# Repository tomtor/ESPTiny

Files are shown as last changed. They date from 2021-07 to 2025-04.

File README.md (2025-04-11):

# ATtiny84/16x4/x02 and ESP-01 (ESP8266) KiCad PCB and example code

## Usage

The main function of the ATtiny is acting as a battery friendly low power co-processor for the ESP.
A bit like the ULP low power co-processor of the ESP32, except with a lot more IO functions and program memory.

ATtiny and ESP combined use 22uA in sleep mode or even less when the ESP
is switched off by the ATtiny with CS.

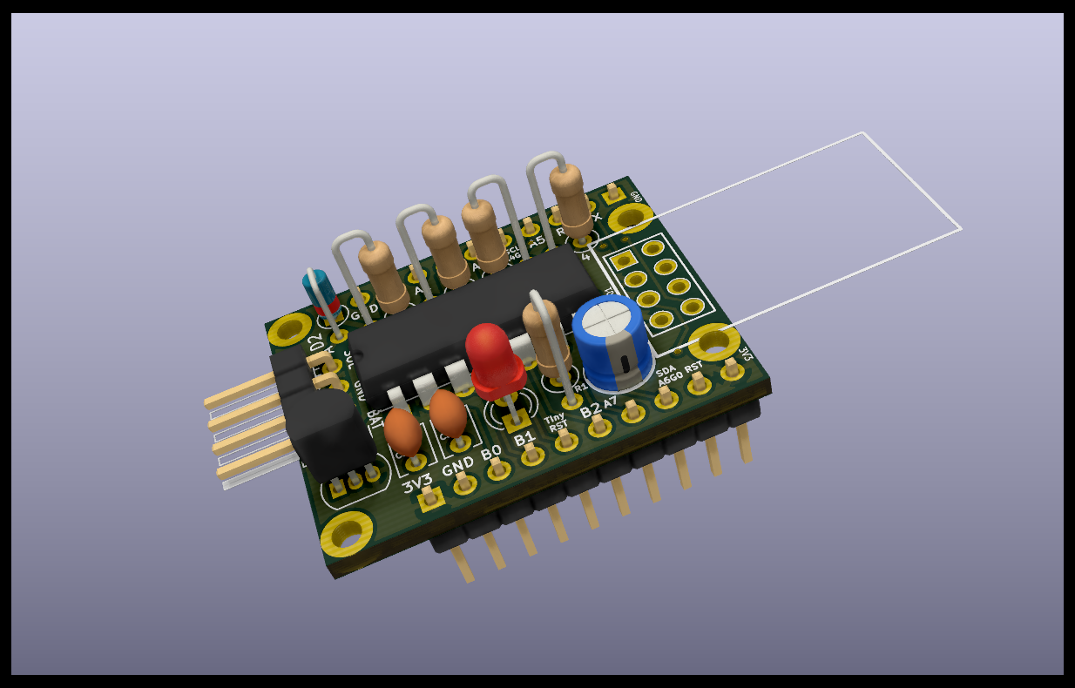
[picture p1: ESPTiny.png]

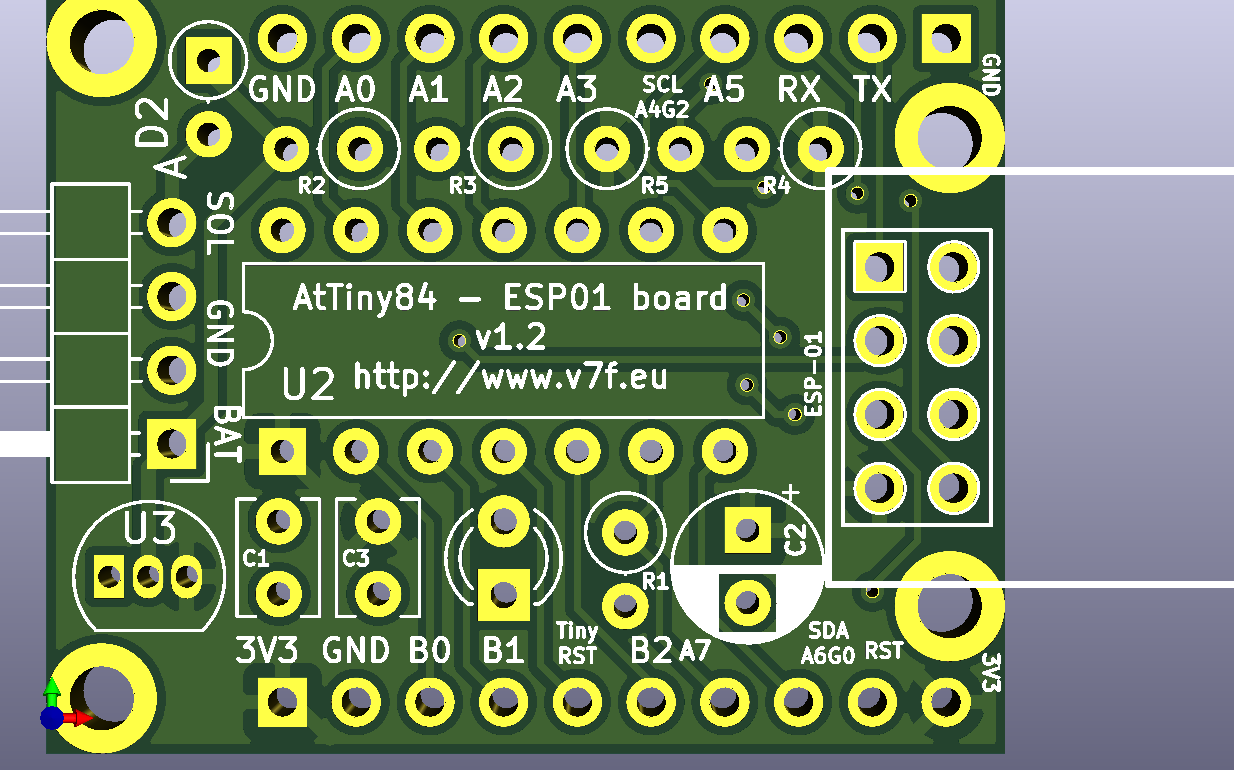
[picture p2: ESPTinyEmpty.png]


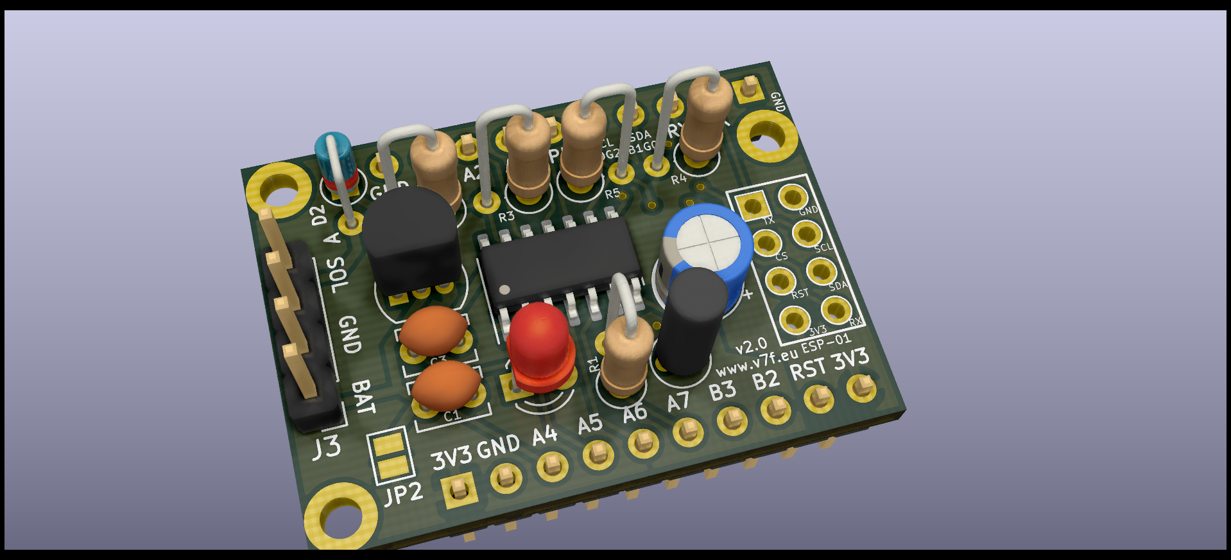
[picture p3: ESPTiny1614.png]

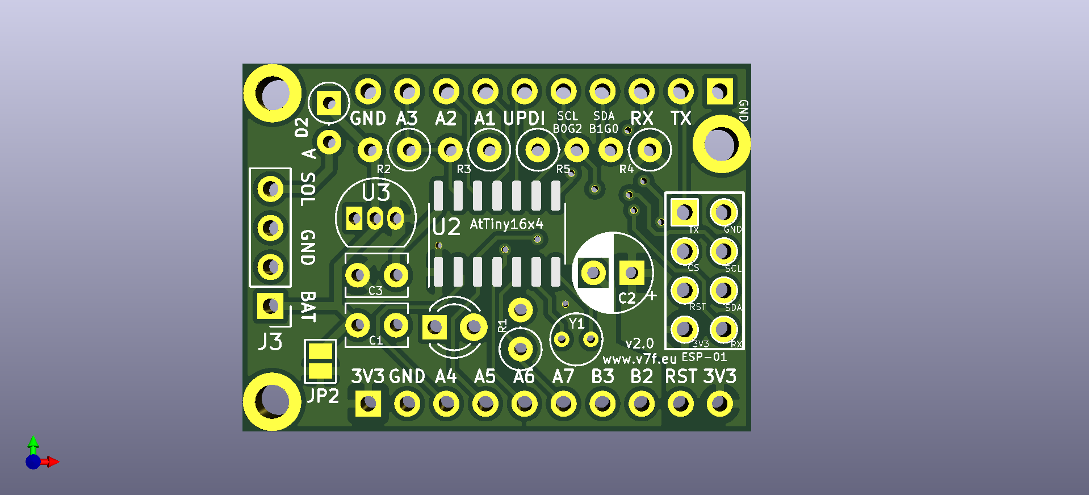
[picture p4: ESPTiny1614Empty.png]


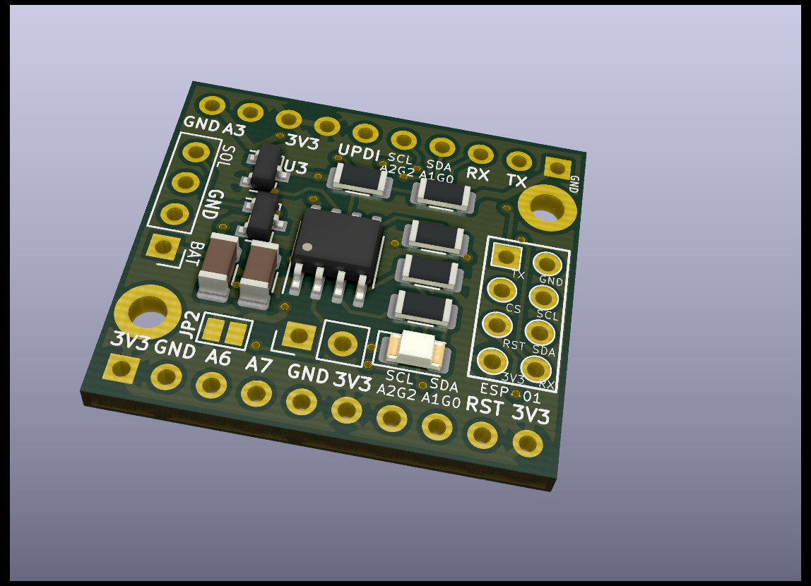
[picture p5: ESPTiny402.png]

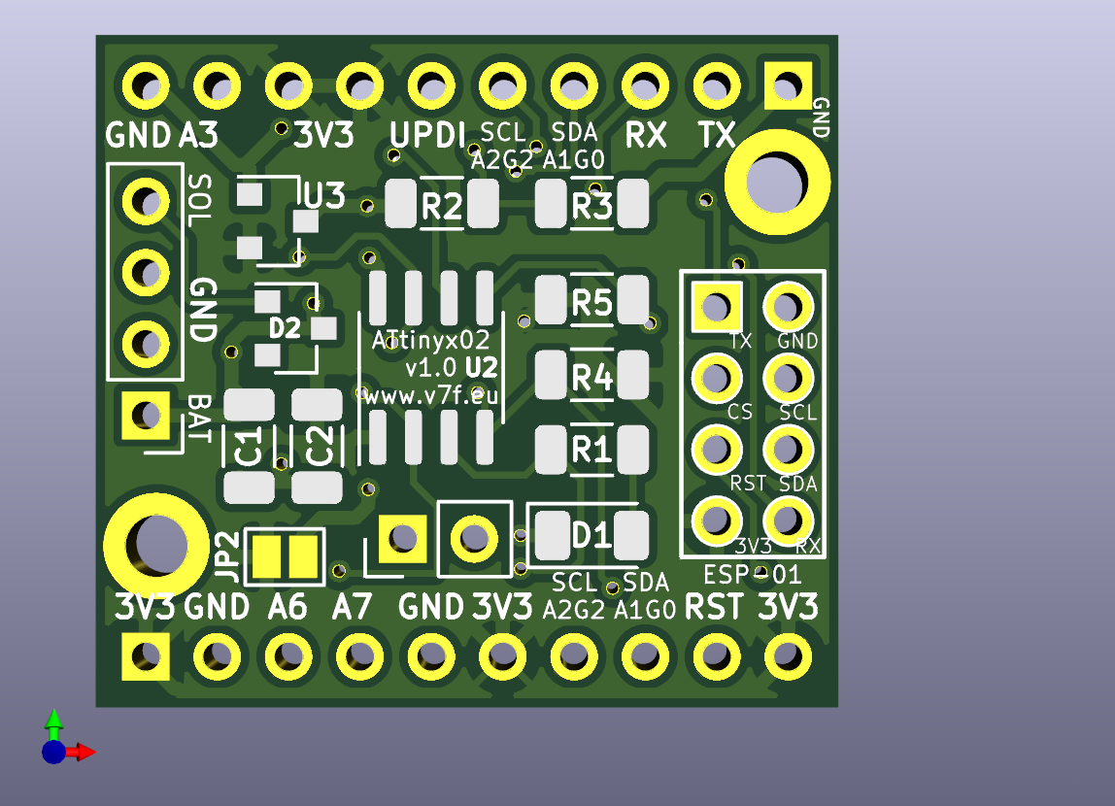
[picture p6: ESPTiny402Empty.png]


Usable on breadboard (ATtiny84: 9 rows high, leaves 2 rows empty and ATtiny16x4: 8 rows high) OR stand alone.

3 PCB designs: ATtiny84 or ATtiny16x4 or ATtinyx02

All components / features are optional:

- ATtiny84 or ATtiny1604 / ATtiny1614 or ATtiny202 / ATtiny402
- ESP-01 (When not used the connections/space can be used for any other (I2C) device)
- LED with resistor
- MCP1700 low quiescent current regulator
- BAT85 diode for Solar Charging panel (see https://www.thethingsnetwork.org/labs/story/a-cheap-stm32-arduino-node/step/solar-power)
- Voltage divider for measuring battery voltage
- Decoupling capacitors
- I2C communication between ESP and ATtiny (with optional 4k7 pull-up)
- ATtiny can restart ESP by pulling ESP Reset low

## Example code

The ATtiny wakes up the ESP every 10 minutes by pulling RST low and sends a counter and the supply voltage to it.

### OTA for the ESP
OTA for ESP program updates is activated for 20s when the I2C communication fails.
This can be triggered by resetting the ESP by pulling the RST line low.
Because the ATtiny is most of the time sleeping
the I2C communication will fail.

There is a small chance that the ATtiny will reset the ESP during upload when the 10 minute interval is completed.
You can prevent this by pulling the ATtiny RST low when using OTA, or just upload again.

## Schemas

https://github.com/tomtor/ESPTiny/raw/master/ESPTiny.pdf
Schema

https://github.com/tomtor/ESPTiny/raw/master/ESPTiny1614.pdf
Schema

https://github.com/tomtor/ESPTiny/raw/master/ESPTiny402.pdf
Schema

## Credits

https://github.com/jdunmire/kicad-ESP8266

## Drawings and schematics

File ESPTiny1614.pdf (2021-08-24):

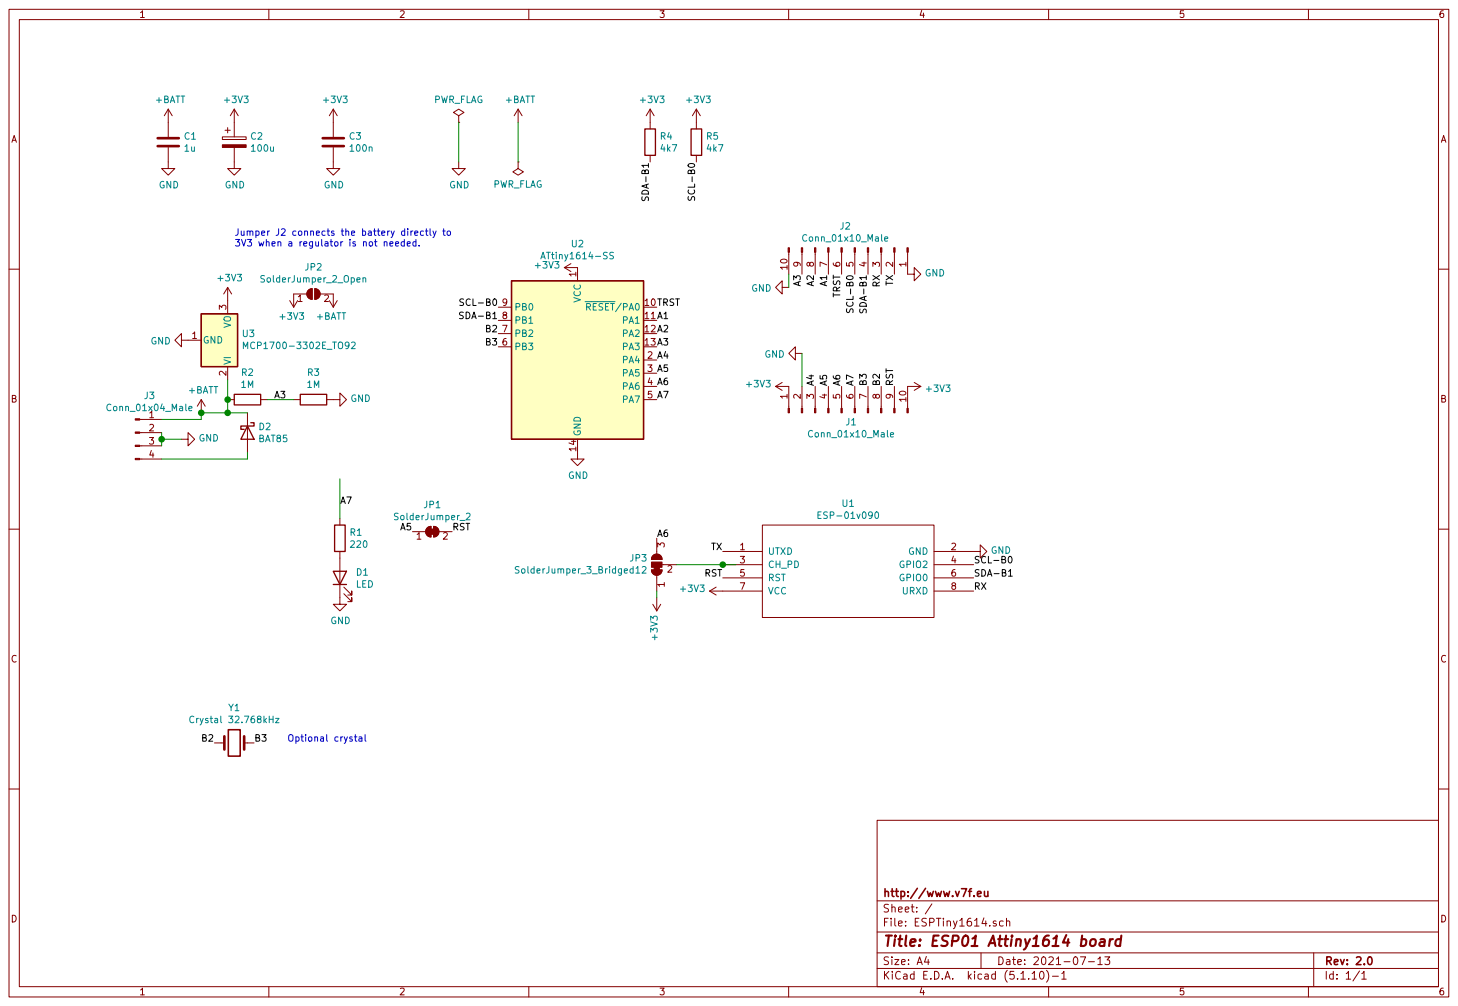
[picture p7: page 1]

Jumper J2 connects the battery directly to
3V3 when a regulator is not needed.

1 RESET/PA0 10 PA1 11 PA2 12 PA3 13 GND 14 PA4 2 PA5 3 PA6 4 PA7 5 PB3 6 PB2 7 PB1 8 PB0 9 U2 ATtiny1614-SS UTXD 1 GND 2 CH_PD 3 GPIO2 4 RST 5 GPIO0 6 VCC 7 URXD 8 U1 ESP-01v090 GND

File: ESPTiny1614.sch Sheet: / http://www.v7f.eu

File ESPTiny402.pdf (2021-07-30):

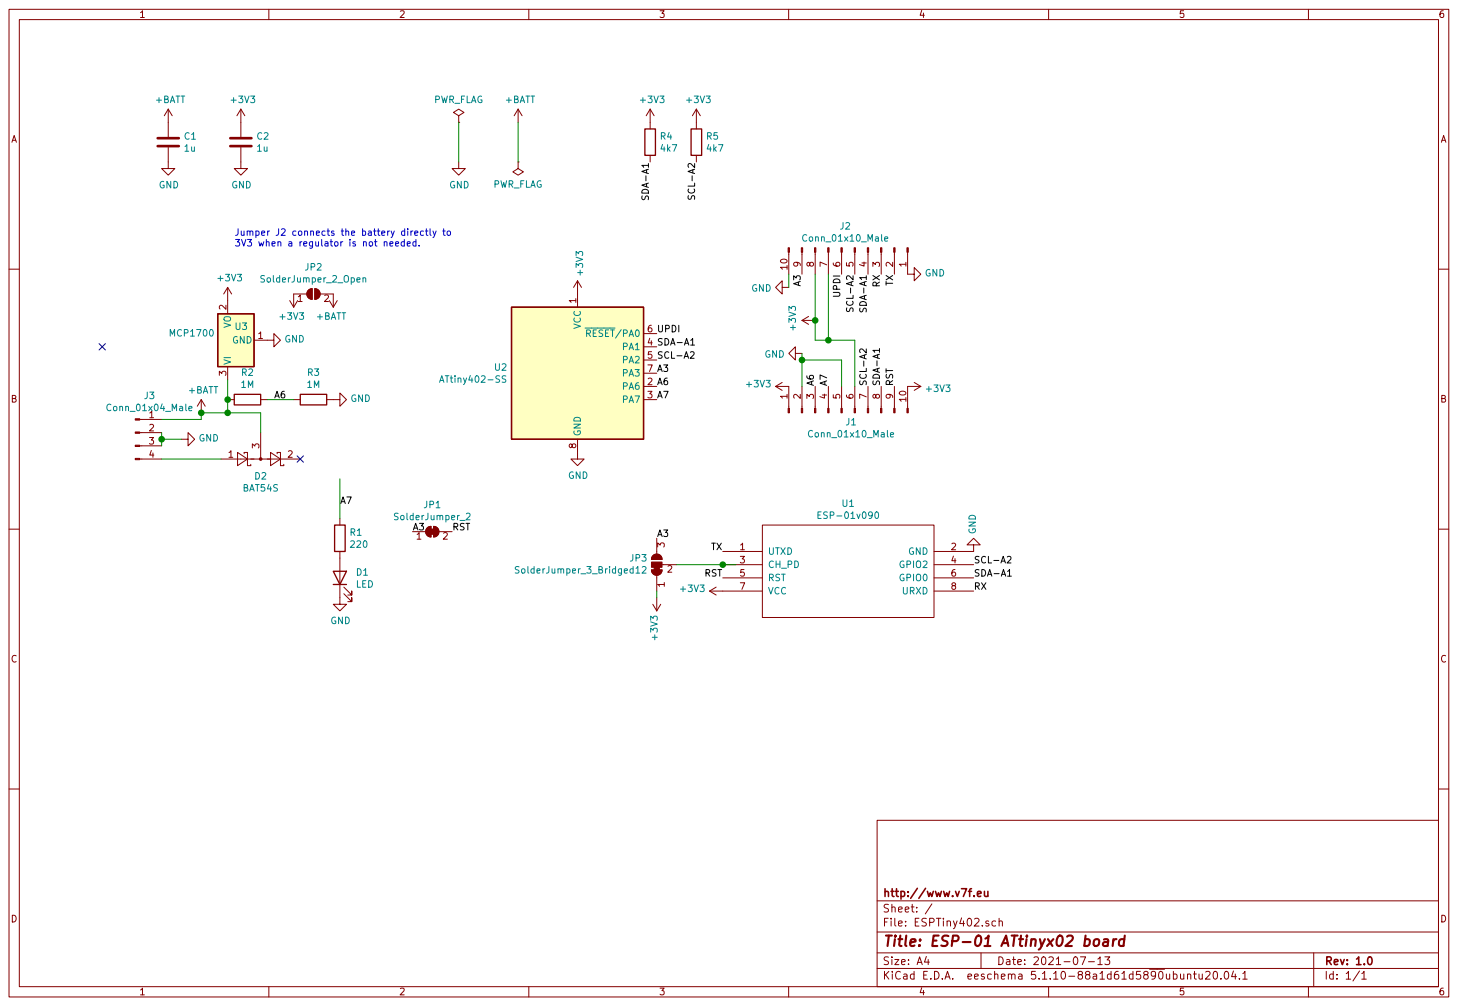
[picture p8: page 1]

Jumper J2 connects the battery directly to
3V3 when a regulator is not needed.

File: ESPTiny402.sch Sheet: / http://www.v7f.eu

Id: 1/1 Title: ESP-01 ATtinyx02 board

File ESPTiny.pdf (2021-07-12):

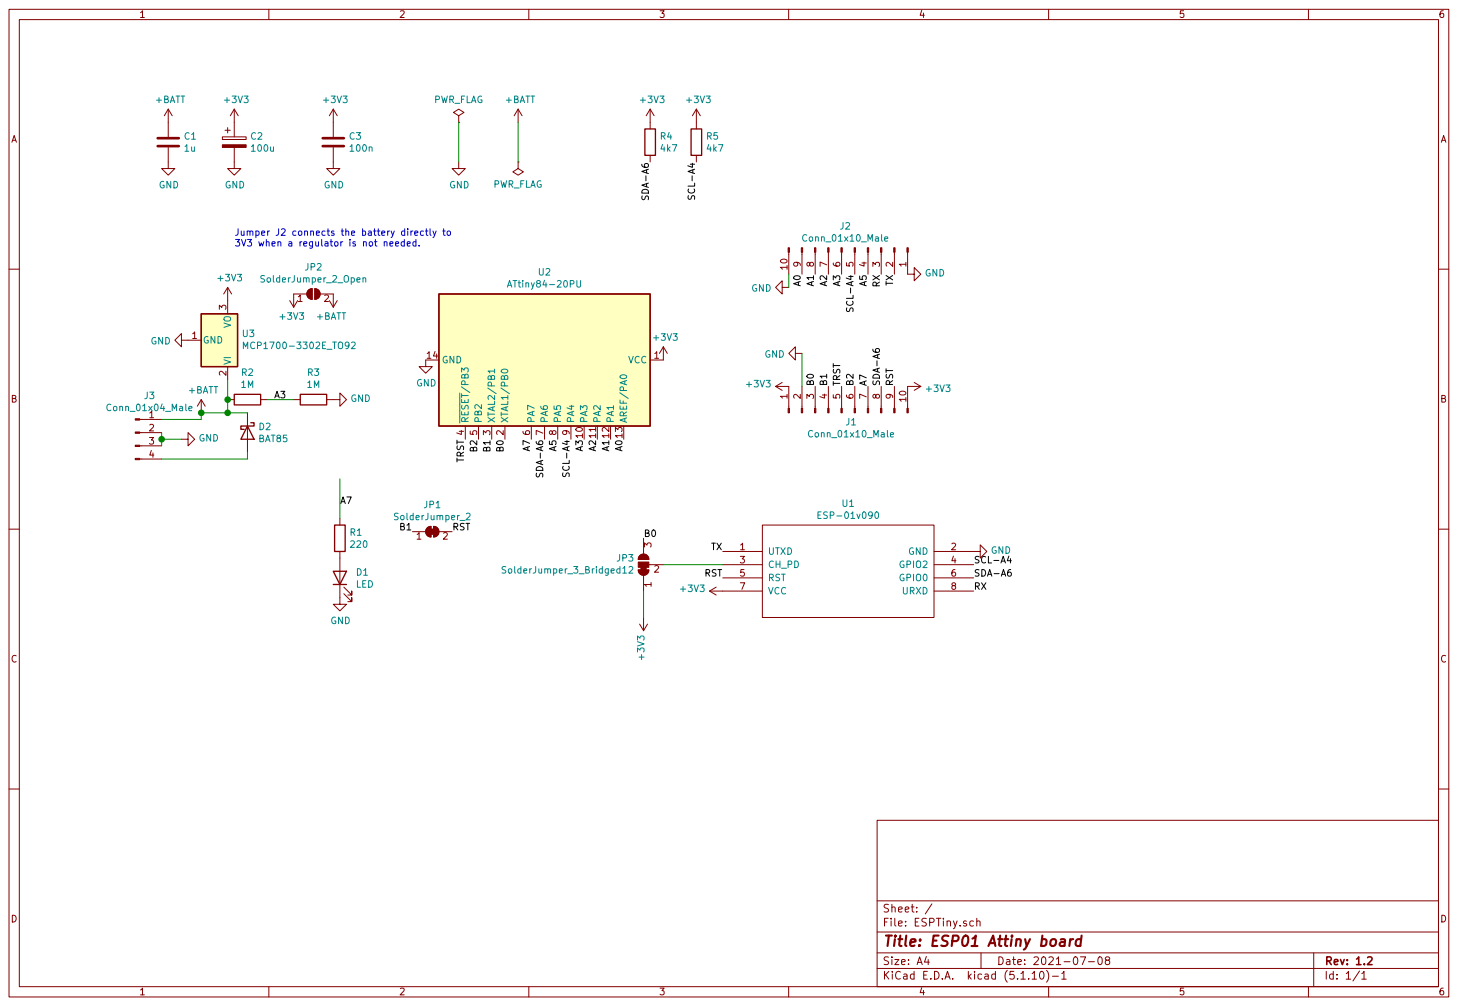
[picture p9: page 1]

Jumper J2 connects the battery directly to
3V3 when a regulator is not needed.

File: ESPTiny.sch Sheet: /
Id: 1/1 Title: ESP01 Attiny board

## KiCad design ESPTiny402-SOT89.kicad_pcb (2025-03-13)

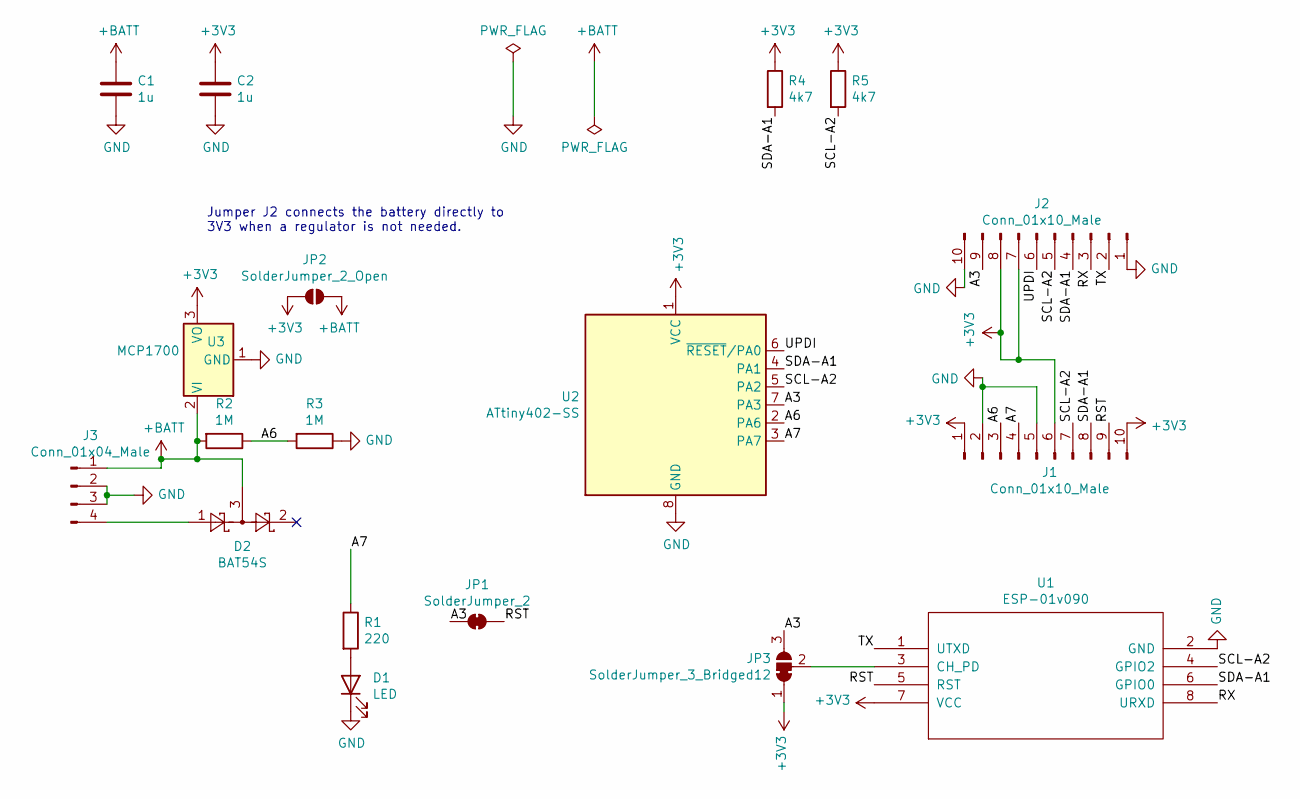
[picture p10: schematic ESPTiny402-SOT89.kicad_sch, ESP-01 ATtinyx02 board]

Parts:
C1, C2: 1u; C_1206_3216Metric
D1: LED; LED_1206_3216Metric
D2: BAT54S; SOT-23
J1, J2: Conn_01x10_Male; PinHeader_1x10_P2.54mm_Vertical
J3: Conn_01x04_Male; PinHeader_1x04_P2.54mm_Vertical
JP1: SolderJumper_2; SolderJumper-2_P1.3mm_Bridged_RoundedPad1.0x1.5mm
JP2: SolderJumper_2_Open; SolderJumper-2_P1.3mm_Open_Pad1.0x1.5mm
JP3: SolderJumper_3_Bridged12; SolderJumper-3_P1.3mm_Bridged12_RoundedPad1.0x1.5mm_NumberL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
R1: 220; R_1206_3216Metric
R2, R3: 1M; R_1206_3216Metric
R4, R5: 4k7; R_1206_3216Metric
U1: ESP-01v090; ESP-01
U2: ATtiny402-SS; SOIC-8_3.9x4.9mm_P1.27mm
U3: MCP1700; SOT-89-3

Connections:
+3V3: C2.1, J1.1, J1.6, J1.10, J2.7, J2.8, JP2.1 (A), JP3.1 (A), R4.1, R5.1, U1.7 (VCC), U2.1 (VCC), U3.3 (VO)
+BATT: C1.1, D2.3, J3.1, JP2.2 (B), R2.2, U3.2 (VI)
/A3: J2.9, JP1.1 (A), JP3.3 (B), U2.7 (PA3)
/A6: J1.3, R2.1, R3.2, U2.2 (PA6)
/A7: J1.4, R1.1, U2.3 (PA7)
/RST: J1.9, JP1.2 (B), U1.5 (RST)
/RX: J2.3, U1.8 (URXD)
/SCL-A2: J1.7, J2.5, R5.2, U1.4 (GPIO2), U2.5 (PA2)
/SDA-A1: J1.8, J2.4, R4.2, U1.6 (GPIO0), U2.4 (PA1)
/TX: J2.2, U1.1 (UTXD)
/UPDI: J2.6, U2.6 (~RESET/PA0)
GND: C1.2, C2.2, D1.1 (K), J1.2, J1.5, J2.1, J2.10, J3.2, J3.3, R3.1, U1.2 (GND), U2.8 (GND), U3.1 (GND)
unnamed: D1.2 (A), R1.2
unnamed: D2.1, J3.4
unnamed: JP3.2 (C), U1.3 (CH_PD)

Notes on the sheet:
Jumper J2 connects the battery directly to 3V3 when a regulator is not needed.

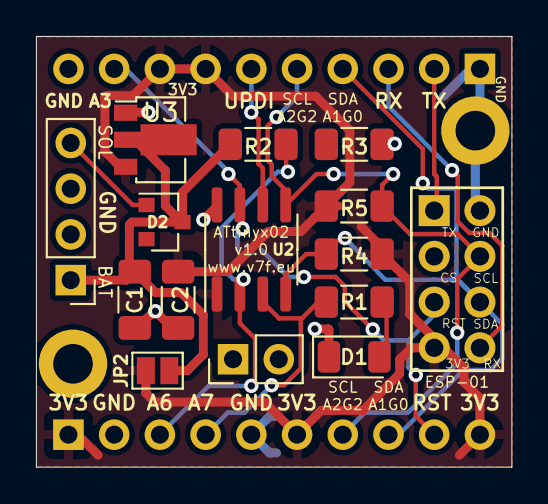
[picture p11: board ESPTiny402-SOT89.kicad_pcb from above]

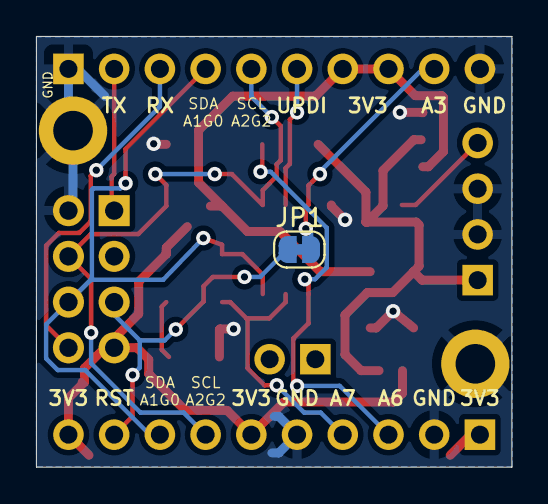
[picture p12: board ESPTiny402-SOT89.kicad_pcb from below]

Board: 2 copper layers, 26.4 x 23.9 mm, 17 parts (3 on the bottom side), 14 nets.

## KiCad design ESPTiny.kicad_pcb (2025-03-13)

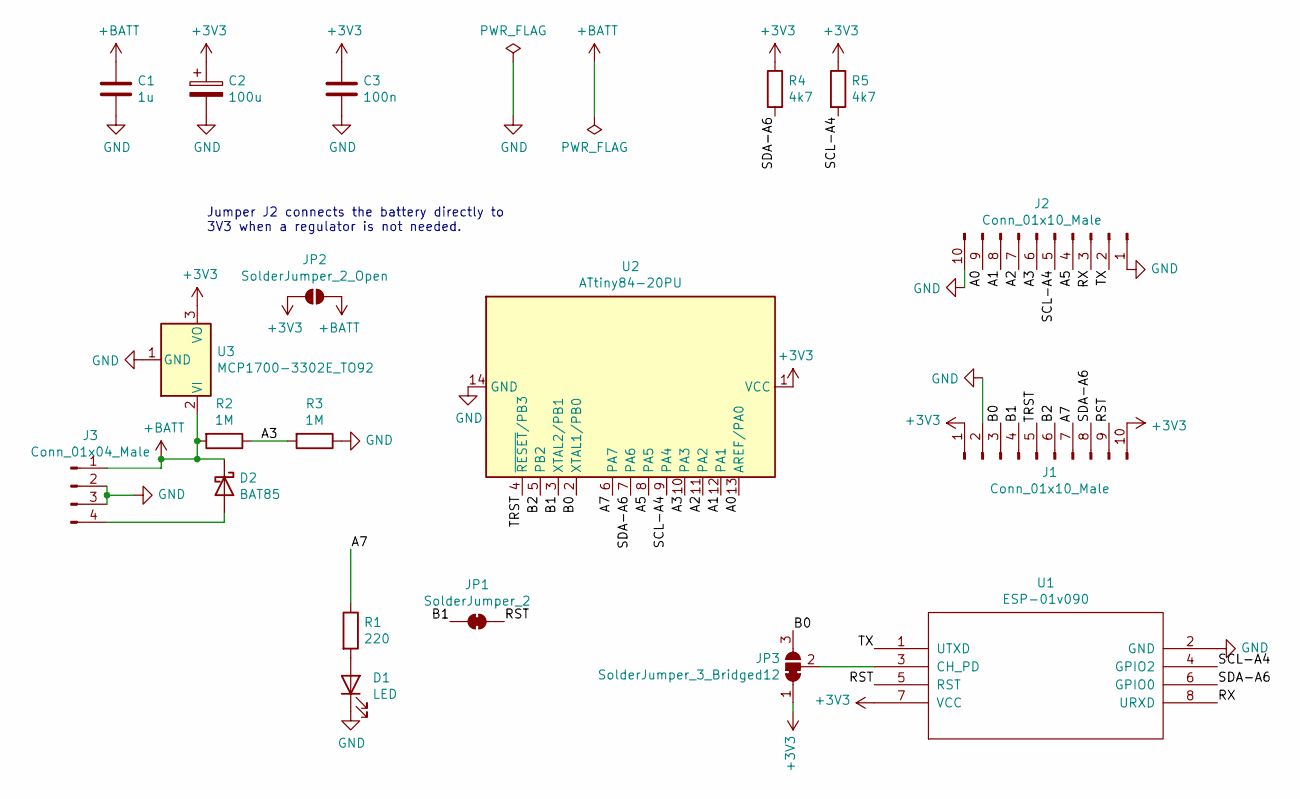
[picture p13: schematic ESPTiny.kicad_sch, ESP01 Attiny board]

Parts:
C1: 1u; C_Disc_D3.8mm_W2.6mm_P2.50mm
C2: 100u; CP_Radial_D5.0mm_P2.50mm
C3: 100n; C_Disc_D3.8mm_W2.6mm_P2.50mm
D1: LED; LED_D3.0mm
D2: BAT85; D_DO-35_SOD27_P2.54mm_Vertical_AnodeUp
J1, J2: Conn_01x10_Male; PinHeader_1x10_P2.54mm_Vertical
J3: Conn_01x04_Male; PinHeader_1x04_P2.54mm_Horizontal
JP1: SolderJumper_2; SolderJumper-2_P1.3mm_Bridged_RoundedPad1.0x1.5mm
JP2: SolderJumper_2_Open; SolderJumper-2_P1.3mm_Open_RoundedPad1.0x1.5mm
JP3: SolderJumper_3_Bridged12; SolderJumper-3_P1.3mm_Bridged12_RoundedPad1.0x1.5mm_NumberL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
R1: 220; R_Axial_DIN0207_L6.3mm_D2.5mm_P2.54mm_Vertical
R2, R3: 1M; R_Axial_DIN0207_L6.3mm_D2.5mm_P2.54mm_Vertical
R4, R5: 4k7; R_Axial_DIN0207_L6.3mm_D2.5mm_P2.54mm_Vertical
U1: ESP-01v090; ESP-01
U2: ATtiny84-20PU; DIP-14_W7.62mm
U3: MCP1700-3302E_TO92; TO-92_Inline

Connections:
+3V3: C2.1, C3.1, J1.1, J1.10, JP2.1 (A), JP3.1 (A), R4.1, R5.1, U1.7 (VCC), U2.1 (VCC), U3.3 (VO)
+BATT: C1.1, D2.1 (K), J3.1, JP2.2 (B), R2.2, U3.2 (VI)
/A0: J2.9, U2.13 (AREF/PA0)
/A1: J2.8, U2.12 (PA1)
/A2: J2.7, U2.11 (PA2)
/A3: J2.6, R2.1, R3.2, U2.10 (PA3)
/A5: J2.4, U2.8 (PA5)
/A7: J1.7, R1.1, U2.6 (PA7)
/B0: J1.3, JP3.3 (B), U2.2 (XTAL1/PB0)
/B1: J1.4, JP1.1 (A), U2.3 (XTAL2/PB1)
/B2: J1.6, U2.5 (PB2)
/RST: J1.9, JP1.2 (B), U1.5 (RST)
/RX: J2.3, U1.8 (URXD)
/SCL-A4: J2.5, R5.2, U1.4 (GPIO2), U2.9 (PA4)
/SDA-A6: J1.8, R4.2, U1.6 (GPIO0), U2.7 (PA6)
/TRST: J1.5, U2.4 (~RESET/PB3)
/TX: J2.2, U1.1 (UTXD)
GND: C1.2, C2.2, C3.2, D1.1 (K), J1.2, J2.1, J2.10, J3.2, J3.3, R3.1, U1.2 (GND), U2.14 (GND), U3.1 (GND)
unnamed: D1.2 (A), R1.2
unnamed: D2.2 (A), J3.4
unnamed: JP3.2 (C), U1.3 (CH_PD)

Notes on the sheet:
Jumper J2 connects the battery directly to 3V3 when a regulator is not needed.

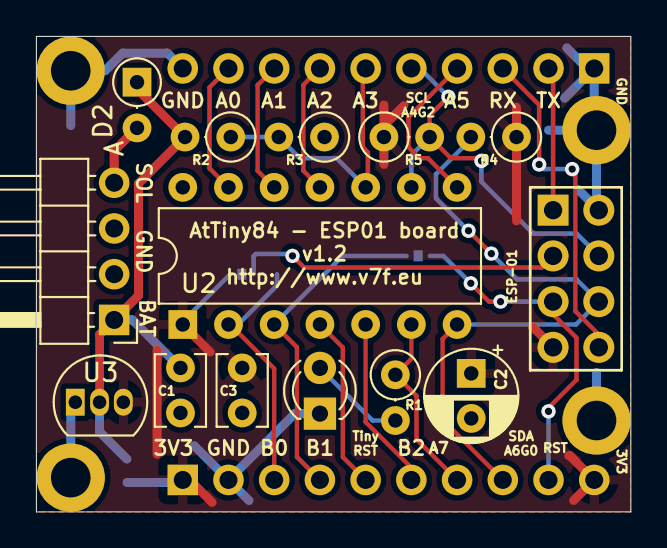
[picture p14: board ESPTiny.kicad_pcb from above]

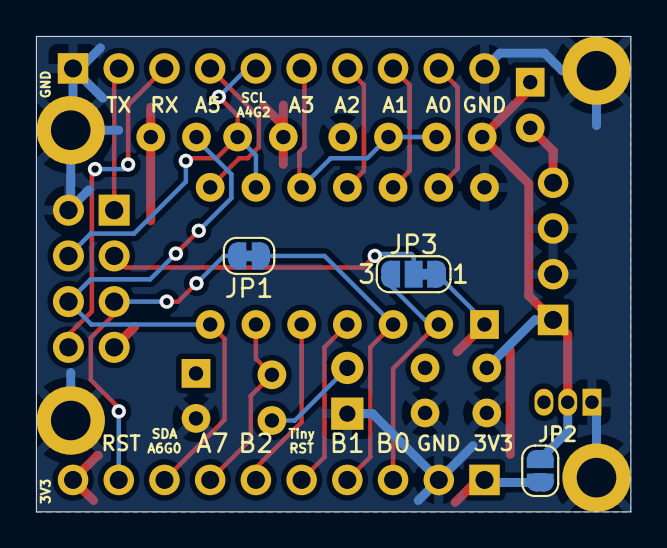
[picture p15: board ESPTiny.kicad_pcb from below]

Board: 2 copper layers, 33.0 x 26.4 mm, 19 parts (5 on the bottom side), 21 nets.

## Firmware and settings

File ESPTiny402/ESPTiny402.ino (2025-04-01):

// #include <Event.h>
// #include <Logic.h>

#include <avr/sleep.h>

#define TEST_TIME 0

#define led       PIN_PA7
#define reset_ESP PIN_PB3

#define USE_BME	0
#define USE_ESP 0

#define RTC_PERIOD	0x8000 // Overflow at 32768 ticks from RTC
#define RTC_MILLIS	1000   // That matches 1000ms

#if USE_ESP
#include <Wire.h>
#endif

#if USE_BME
#include <BME280I2C.h>

BME280I2C bme;
#endif

#define SLEEPINT	// Do not count PIT interrupts but use RTC interrupt at exact time


void RTC_init(void)
{
  /* Initialize RTC: */
  while (RTC.STATUS > 0)
    ;                                   /* Wait for all register to be synchronized */
  RTC.PER = RTC_PERIOD - 1;		/* 1 sec overflow */
  RTC.CLKSEL = RTC_CLKSEL_INT32K_gc;    /* 32.768kHz Internal Ultra-Low-Power Oscillator (OSCULP32K) */

  // For overflow ticks while sleeping:
  // RTC.INTCTRL = RTC_OVF_bm;

  RTC.CTRLA |= RTC_RTCEN_bm | RTC_RUNSTDBY_bm;

#ifndef SLEEPINT
  RTC.PITCTRLA = RTC_PITEN_bm;    /* Disable PIT counter, should not be done, see erratum */
#endif
}

#ifdef SLEEPINT
volatile uint8_t sleep_cnt;

ISR(RTC_CNT_vect)
{
  // if (RTC.INTFLAGS & RTC_CMP_bm) {
    sleep_cnt--;
    RTC.INTFLAGS = RTC_CMP_bm;          /* Clear interrupt flag by writing '1' (required) */
  // }
  // if (RTC.INTFLAGS & RTC_OVF_bm) {
  //   RTC.INTFLAGS = RTC_OVF_bm;          /* Clear interrupt flag by writing '1' (required) */
  // }
}
#else
volatile uint16_t ticks;

ISR(RTC_PIT_vect)
{
  if (ticks)
    ticks--;

  RTC.PITINTFLAGS = RTC_PI_bm;          /* Clear interrupt flag by writing '1' (required) */
}
#endif


void sleepDelay(uint16_t n)
{
#ifndef SLEEPINT
  uint16_t cticks;
  uint8_t period;

  if (n < 100) {
      period = RTC_PERIOD_CYC8_gc; // 1/4 ms
      cticks = (n << 2);
  } else if (n < 1000) {
      period = RTC_PERIOD_CYC64_gc; // 2 ms
      cticks = (n >> 1);
  } else if (n < 5000) {
      period = RTC_PERIOD_CYC1024_gc; // 32 ms
      cticks = (n >> 5);
  } else {
      period = RTC_PERIOD_CYC8192_gc; // 256 ms
      cticks = (n >> 8);
  }

  while (RTC.PITSTATUS & RTC_CTRLBUSY_bm)  // Wait for new settings to synchronize
    ;
  RTC.PITCTRLA = period | RTC_PITEN_bm;    // Enable PIT counter: enabled
 
  RTC.PITINTCTRL |= RTC_PI_bm;             /* PIT Interrupt: enabled */
  ticks = cticks;

  while (ticks)
    sleep_cpu();

  //RTC.PITCTRLA = 0;    /* Disable PIT counter, should not be done, see erratum */
  RTC.PITINTCTRL &= ~RTC_PI_bm;           /* PIT Interrupt: disabled */
#else
  while (RTC.STATUS /* & RTC_CMPBUSY_bm */)  // Wait for new settings to synchronize
    ;

  uint32_t tdelay;
  noInterrupts();
  uint16_t cnt = RTC.CNT;
  RTC.CMP = (cnt + (tdelay = (n * 32UL) + uint16_t(n / 4 * 3))) & (RTC_PERIOD-1); // With this calculation every multiple of 4ms is exact!
  // Note 20011 ms = 655360 ticks = 20 overflows exactly, so CMP will be set to the current CNT and this works OK
  // 9005 will set CMP to CNT+1

  if (RTC.CNT == RTC.CMP) {
    tdelay -= RTC_PERIOD;
  } else if (((RTC.CMP - cnt) & (RTC_PERIOD-1)) <= 2) { // overflow is/was near, 4Mhz clock or faster
    while (RTC.CNT != RTC.CMP) // Wait for it...
      ;
    tdelay -= RTC_PERIOD;
  }

#if RTC_PERIOD != 0x8000
  sleep_cnt = tdelay / RTC_PERIOD + 1; // Calculate number of wrap arounds (overflows)
#else
  sleep_cnt = 2 * (tdelay >> 16) + ((tdelay & 0x8000) ? 2 : 1); // 10 times faster...
#endif
  RTC.INTFLAGS = RTC_CMP_bm; // Clear interrupt flag by writing '1'
  RTC.INTCTRL |= RTC_CMP_bm;
  interrupts();
  uint64_t start = millis();
  while (sleep_cnt) {
    sleep_cpu();
  }
#if !TEST_TIME
  noInterrupts();
  set_millis(start + n);
  interrupts();
#endif

  RTC.INTCTRL &= ~RTC_CMP_bm;
#endif
}

#if 1
unsigned int getBandgap ()
{
#if 0
  analogReference(INTERNAL1V1);
  uint16_t Vcc_value = 0x400 * 1100UL / analogRead(ADC_INTREF); /* calculate the Vcc value */
#else
  VREF.CTRLA = VREF_ADC0REFSEL_1V1_gc;    /* Set the Vref to 1.1V*/

  /* The following section is partially taken from Microchip App Note AN2447 page 13*/

  ADC0.MUXPOS = ADC_MUXPOS_INTREF_gc    /* ADC internal reference, the Vbg*/;
  ADC0.CTRLC = ADC_PRESC_DIV4_gc        /* CLK_PER divided by 4 */
               | ADC_REFSEL_VDDREF_gc   /* Vdd (Vcc) be ADC reference */
               | 0 << ADC_SAMPCAP_bp;   /* Sample Capacitance Selection: disabled */

  uint16_t Vcc_value = 0;                /* measured Vcc value */

  ADC0.CTRLA = 1 << ADC_ENABLE_bp     /* ADC Enable: enabled */
               | 1 << ADC_FREERUN_bp  /* ADC Free run mode: enabled */
               | ADC_RESSEL_10BIT_gc; /* 10-bit mode */

  ADC0.COMMAND |= 1;                  // start running ADC
  while (!(ADC0.INTFLAGS & ADC_RESRDY_bm));

  Vcc_value = 0x400 * 1100UL / ADC0.RES /* calculate the Vcc value */;
#endif
  return Vcc_value;
} // end of getBandgap
#endif

#if 1
unsigned int getBattery ()
{
  unsigned int val = analogRead(PIN_PA3);

  // 3.0v regulator with voltage divider (820k/820k):
  const float Vref = 3000,
              R = 820000,
              Rintern = 100000000, // ATtiny ADC internalresistance
              Rpar = (R * Rintern) / (R + Rintern);
  const unsigned long scale = Vref * (R + Rpar) / Rpar;
  unsigned int results = scale * val / 0x400;

  return results;
} // end of getBattery
#endif


void blinkN(uint8_t n, uint8_t l = led)
{
  for (uint8_t i = 0; i < n; i++) {
    digitalWriteFast(l, HIGH);
    sleepDelay(2);
    digitalWriteFast(l, LOW);
    sleepDelay(700);
  }
}


// the setup routine runs once when you press reset:
void setup() {
  Serial.swap(1); // A1,A2 = TX,RX
  Serial.begin(9600);
  Serial.println("Start"); Serial.flush();

  RTC_init();                           /* Initialize the RTC timer */
#ifdef SLEEPINT
#if TEST_TIME
  set_sleep_mode(SLEEP_MODE_IDLE);
#else
  set_sleep_mode(SLEEP_MODE_STANDBY);
#endif
#else
  set_sleep_mode(SLEEP_MODE_PWR_DOWN);
#endif
  sleep_enable();                       /* Enable sleep mode, but not going to sleep yet */

  // pinMode(PIN_PA1, INPUT_PULLUP);
  pinMode(PIN_PA2, INPUT_PULLUP);
  pinMode(PIN_PA3, INPUT_PULLUP);
  //  pinMode(PIN_PA4, INPUT_PULLUP);
  //  pinMode(PIN_PA5, INPUT_PULLUP);
  pinMode(PIN_PA6, INPUT_PULLUP);
  pinMode(PIN_PA7, INPUT_PULLUP);
  //  pinMode(PIN_PB0, INPUT_PULLUP);
  //  pinMode(PIN_PB1, INPUT_PULLUP);
  //  pinMode(PIN_PB2, INPUT_PULLUP);
  //  pinMode(PIN_PB3, INPUT_PULLUP);

  pinMode(led, OUTPUT);
  //Serial.println("Blink"); Serial.flush();

  for (byte i = 0; i < 3; i++) {
    blinkN(1, led);
  }

#if TEST_TIME
 while (1) {
    blinkN(1);
    uint16_t testn;
    switch (random() & 0x07) {
      case 0: testn = 9005; break;
      case 1: testn = 29016; break;
      case 2: testn = 20011; break;
      default:
          testn = random(500, 2500);
    }
    //Serial.println(testn); Serial.flush();
    uint32_t start = millis();
    sleepDelay(testn);
    // int rand = random(1,1000);
    // sleepDelay(rand);
    // Serial.flush();
    int32_t delta = millis() - start;
    Serial.print(delta); Serial.print(' '); Serial.println(testn); Serial.flush();
    if (delta < testn - 500 || delta > testn + 500) {
      Serial.println("Error"); Serial.flush();
      while (1) blinkN(1);
    }
  }
#endif

  sleepDelay(5000);

  // pinMode(PIN_PA2, OUTPUT);
  // Event0.set_generator(gen::rtc_ovf);
  // Event0.set_user(user::evouta_pin_pa2);
  // Event0.start();
  // pinMode(PIN_PA7, OUTPUT);
  // Logic1.enable = true;
  // Logic1.input0 = logic::in::tca0;
  // Logic1.input1 = logic::in::tca0;
  // Logic1.input2 = logic::in::tca0;
  // Logic1.output = logic::out::enable;
  // Logic1.filter = logic::filter::disable;
  // Logic1.truth = 0x55;
  // Logic1.init();
  // Logic1.start();
}


unsigned voltage;

#if USE_ESP
volatile unsigned cnt;

// function that executes whenever data is requested by master
// this function is registered as an event
void requestEvent() {
  Wire.write(cnt >> 8);
  Wire.write(cnt & 0xF0);
  Wire.write(voltage >> 8);
  Wire.write(voltage & 0xFF);

  ++cnt;
}
#endif

// the loop routine runs over and over again forever:
void loop() {

  //unsigned int v = voltage = getBattery();

  unsigned int v = voltage = getBandgap();
  blinkN(v / 1000);
  sleepDelay(1500);
  blinkN((v % 1000) / 100);
  sleepDelay(1500);
  blinkN((v % 100) / 10);

  // sleepDelay(5000);
  // while (1)
  //   digitalWriteFast(led, RTC.CNT & 1 ? HIGH: LOW);

  sleepDelay(5000);
  for (int i= 1; i <= 10; i++) {
    sleepDelay(1);
    digitalWriteFast(led, HIGH);
    sleepDelay(i);
    digitalWriteFast(led, LOW);
  }
  sleepDelay(5000);

#if USE_BME
  Wire.begin(1);                // join i2c bus with address #1
  bme.begin();
#if 0
  float temp(NAN), hum(NAN), pres(NAN);

  BME280::TempUnit tempUnit(BME280::TempUnit_Celsius);
  BME280::PresUnit presUnit(BME280::PresUnit_Pa);

  bme.read(pres, temp, hum, tempUnit, presUnit);
#else
  static float oldtemp;
  float temp;
  if ((temp = bme.temp()) == oldtemp)
    return;
  oldtemp = temp;
#endif
#endif

#if USE_ESP
  digitalWrite(reset_ESP, LOW);
  pinMode(reset_ESP, OUTPUT);
  sleepDelay(32);
  pinMode(reset_ESP, INPUT_PULLUP);

  sleepDelay(3000);

  auto startcnt = cnt;

  Wire.begin(1);                // join i2c bus with address #1
  Wire.onRequest(requestEvent); // register event

  auto end = millis() + 4000;
  while (cnt == startcnt && millis() < end)
    ;
  delay(200);
  Wire.end();
#endif
}

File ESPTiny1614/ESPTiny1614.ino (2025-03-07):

#define led       PIN_PA7
#define ON_TIME   3

// #define reset_ESP PIN_PB3
#define reset_ESP PIN_PA5

#define USE_BME  0
#define USE_ESP 0

#define USE_OSC 0

// Slowdown 2 sec every 24 hours:
// 24 * 3600 / 2 = 43200 ticks with 2 second interval in 24 hours.
// Adjustment is in steps of 2 seconds (a ticks increments the clock with 2 seconds).

//#define ADJUST 65535 // Slightly less than 1 second every 24 hours


#if USE_ESP || USE_BME
#include <Wire.h>
#endif

#include <avr/sleep.h>


#if USE_BME
#include <BME280I2C.h>

BME280I2C bme;
#endif

void RTC_init(void)
{
  /* Initialize RTC: */
  while (RTC.STATUS > 0)
  {
    ;                                   /* Wait for all register to be synchronized */
  }
#if USE_OSC
  RTC.CLKSEL = RTC_CLKSEL_INT32K_gc;    /* 32.768kHz Internal Ultra-Low-Power Oscillator (OSCULP32K) */
#else
  _PROTECTED_WRITE(CLKCTRL.XOSC32KCTRLA, 0x3);

  while (RTC.STATUS > 0) ;

  RTC.CLKSEL = RTC_CLKSEL_TOSC32K_gc;   /* 32.768kHz External Oscillator */
#endif

  RTC.PITINTCTRL = RTC_PI_bm;           /* PIT Interrupt: enabled */

  // For 2s overflow ticks while sleeping:
  RTC.INTCTRL = RTC_OVF_bm;
  
  RTC.CTRLA = RTC_PRESCALER_DIV1_gc | RTC_RUNSTDBY_bm | RTC_RTCEN_bm;
}


volatile uint16_t ticks;

ISR(RTC_PIT_vect)
{
  if (ticks)
    ticks--;
  RTC.PITINTFLAGS = RTC_PI_bm;          /* Clear interrupt flag by writing '1' (required) */
}


volatile uint8_t sec2s, hours, minutes; // 2s ticks

ISR(RTC_CNT_vect)
{
  static unsigned int adjust_ticks;

#if ADJUST > 0
  if (++adjust_ticks == ADJUST) {
    adjust_ticks = 0;
  } else {
#elif ADJUST < 0
  if (++adjust_ticks >= -ADJUST && sec2s == 0) {
    adjust_ticks = 0;
    sec2s = 4;
  } else {
#else
  {
#endif
    if (sec2s < 58)
      sec2s += 2;
    else {
      sec2s = 0;
      if (minutes < 59)
        minutes++;
      else {
        minutes = 0;
        if (hours < 23)
          hours++;
        else
          hours = 0;
      }  
    }
  }

  RTC.INTFLAGS = RTC_OVF_bm;          /* Clear interrupt flag by writing '1' (required) */
}


void sleepDelay(uint16_t n)
{
  uint8_t period;

#if 0
  if (n < 10) {
    period = RTC_PERIOD_CYC4_gc; // 1/8 ms
    ticks = (n << 3);
  } else
#endif
  if (n < 10) {
      period = RTC_PERIOD_CYC8_gc; // 1/4 ms
      ticks = (n << 2);
  } else if (n < 1000) {
      period = RTC_PERIOD_CYC64_gc; // 2 ms
      ticks = (n >> 1);
  } else if (n < 5000) {
      period = RTC_PERIOD_CYC1024_gc; // 32 ms
      ticks = (n >> 5);
  } else {
      period = RTC_PERIOD_CYC8192_gc; // 256 ms
      ticks = (n >> 8);
  }

  while (RTC.PITSTATUS & RTC_CTRLBUSY_bm)  // Wait for new settings to synchronize
    ;

  RTC.PITCTRLA = period | RTC_PITEN_bm;    // Enable PIT counter: enabled

  while (RTC.PITSTATUS & RTC_CTRLBUSY_bm)  // Wait for new settings to synchronize
    ;

  while (ticks)
    sleep_cpu();

  RTC.PITCTRLA = 0;    /* Disable PIT counter */
}

#if 1
unsigned int getBandgap ()
{
  analogReference(INTERNAL1V1);
  analogReference(VDD);
  analogRead(ADC_INTREF); // drop first
  return 0x400 * 1100UL / analogRead(ADC_INTREF);
} // end of getBandgap
#endif

#if 1
unsigned int getBattery ()
{
  analogReference(VDD);

  analogRead(PIN_PA3);
  unsigned int val = analogRead(PIN_PA3);

  // 3.3v regulator with voltage divider (820k/820k):
  const float Vref = 3300;
  const unsigned long scale = Vref*2;
  unsigned int results = scale * val / 0x400;

  return results;
} // end of getBattery
#endif


void testDelay(unsigned n, uint8_t l = led)
{
  digitalWrite(l, HIGH);
  sleepDelay(n);
  digitalWrite(l, LOW);
  sleepDelay(3);
}

void blinkN(uint8_t n, uint8_t l = led)
{
  for (uint8_t i = 0; i < n; i++) {
    digitalWrite(l, HIGH);
    sleepDelay(ON_TIME);
    digitalWrite(l, LOW);
    sleepDelay(700);
  }
}


void blinkDec(uint8_t d)
{
  blinkN(d / 10);
  sleepDelay(1500);
  blinkN(d % 10);
  sleepDelay(3000);
}


// the setup routine runs once when you press reset:
void setup() {
  RTC_init();                           /* Initialize the RTC timer */
  set_sleep_mode(SLEEP_MODE_STANDBY);
  sleep_enable();                       /* Enable sleep mode, but not going to sleep yet */

  pinMode(PIN_PA1, INPUT_PULLUP);
  pinMode(PIN_PA2, INPUT_PULLUP);
  pinMode(PIN_PA3, INPUT_PULLUP);
  pinMode(PIN_PA4, INPUT_PULLUP);
  pinMode(PIN_PA5, INPUT_PULLUP);
  pinMode(PIN_PA6, INPUT_PULLUP);
  pinMode(PIN_PA7, INPUT_PULLUP);
  pinMode(PIN_PB0, INPUT_PULLUP);
  pinMode(PIN_PB1, INPUT_PULLUP);
#if !USE_OSC
  pinMode(PIN_PB2, INPUT_PULLUP);
  pinMode(PIN_PB3, INPUT_PULLUP);
#endif

  pinMode(led, OUTPUT);

  for (byte i = 0; i < 3; i++) {
    blinkN(1, led);
  }

  sleepDelay(1000);
  for (int d= 1; d <= 10; d++)
    testDelay(d);
  sleepDelay(5000);
}


unsigned voltage;

volatile unsigned cnt;

#if USE_ESP
// function that executes whenever data is requested by master
// this function is registered as an event
void requestEvent() {
  Wire.write(cnt >> 8);
  Wire.write(cnt & 0xFF);
  Wire.write(voltage >> 8);
  Wire.write(voltage & 0xFF);

  ++cnt;
}
#endif


// the loop routine runs over and over again forever:TRLA = 0;
  // return 
void loop() {

  //delay(1);
  //unsigned int v = voltage = getBattery();
  unsigned int v = voltage = getBandgap();
  blinkDec((v + 50) / 100);

  blinkDec(minutes);

  sleepDelay(5000);
  while (sec2s != 0) {
    if (sec2s % 10 == 0 && sec2s <= 55) {
      blinkN(1);
      sleepDelay(9000);
    } else
      sleepDelay(100);
  }

#if USE_BME
  Wire.begin(1);                // join i2c bus with address #1
  bme.begin();
#if 0
  float temp(NAN), hum(NAN), pres(NAN);

  BME280::TempUnit tempUnit(BME280::TempUnit_Celsius);
  BME280::PresUnit presUnit(BME280::PresUnit_Pa);

  bme.read(pres, temp, hum, tempUnit, presUnit);
#else
  static float oldtemp;
  float temp;
  if ((temp = bme.temp()) == oldtemp)
    return;
  oldtemp = temp;
#endif
#endif

#if USE_ESP
  digitalWrite(reset_ESP, LOW);
  pinMode(reset_ESP, OUTPUT);
  sleepDelay(32);
  pinMode(reset_ESP, INPUT_PULLUP);

  sleepDelay(3000);

  auto startcnt = cnt;

  Wire.begin(1);                // join i2c bus with address #1
  Wire.onRequest(requestEvent); // register event

  auto end = millis() + 4000;
  while (cnt == startcnt && millis() < end)
    ;
  delay(200);
  Wire.end();
#endif
}

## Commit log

2021-06-19 Start on design of combi ESP-01 Attiny84 board
    [ESPTiny.kicad_pcb, ESPTiny.sch]
2021-06-19 Add footprints
    [ESPTiny.kicad_pcb, ESPTiny.sch]
2021-06-27 Without power divider
    [ESPTiny.kicad_pcb, ESPTiny.sch]
2021-06-27 With power divider
    [ESPTiny.kicad_pcb, ESPTiny.sch]
2021-06-27 Add upper fills
    [ESPTiny.kicad_pcb]
2021-06-27 Fix priority 3V3 zone
    [ESPTiny.kicad_pcb]
2021-06-27 Move PWR labels in corner
    [ESPTiny.kicad_pcb]
2021-06-28 Fix ESP CH_PD to 3V3
    [ESPTiny.kicad_pcb, ESPTiny.sch]
2021-06-28 Copper fill
    [ESPTiny.kicad_pcb]
2021-06-28 Copper fill smaller clearance
    [ESPTiny.kicad_pcb]
2021-06-28 Copper fill smaller clearance: 0.27
    [ESPTiny.kicad_pcb]
2021-06-29 Copper fill clearance: 0.3 width: 0.2
    [ESPTiny.kicad_pcb]
2021-06-29 Clean up
    [ESPTiny.kicad_pcb]
2021-06-29 Better GND plane
    [ESPTiny.kicad_pcb]
2021-06-29 D2 silk
    [ESPTiny.kicad_pcb]
2021-06-30 Add 4k7 pull up for I2C
    [ESPTiny.kicad_pcb, ESPTiny.sch]
2021-06-30 extra GND trace
    [ESPTiny.kicad_pcb]
2021-07-01 Add RST jumper
    [ESPTiny.kicad_pcb, ESPTiny.sch]
2021-07-01 Add example Arduino sources
2021-07-01 0.1 production
    [ESPTiny.sch]
2021-07-02 Update schema prints
2021-07-02 Update 3D
    [ESPTiny.kicad_pcb]
2021-07-03 Cleanup and disable pin change interrupt
2021-07-04 Disable wakeup from pin change and add ESP voltage guard
2021-07-04 Disable wakeup from pin change and USI
2021-07-04 attiny watch voltage
2021-07-06 1.1 repositioning
    [ESPTiny.kicad_pcb]
2021-07-07 cleanup tracks
    [ESPTiny.kicad_pcb]
2021-07-08 Rev 1.2 Power bridge, layout
    [ESPTiny.kicad_pcb, ESPTiny.sch]
2021-07-08 Tune pin labels
    [ESPTiny.kicad_pcb]
2021-07-08 Add comment for J2 jumper
    [ESPTiny.sch]
2021-07-09 Replace tantalum C with electrolytic
    [ESPTiny.kicad_pcb, ESPTiny.sch]
2021-07-09 Battery voltage divider from A1 to A3
    [ESPTiny.kicad_pcb, ESPTiny.sch]
2021-07-10 Replace TinyWire with default Wire library
    [ESPTiny44.ino]
2021-07-12 Add CH_PD ESP01 jumper
    [ESPTiny.kicad_pcb, ESPTiny.sch]
2021-07-13 note about pin change
2021-07-14 Add AtTiny16x4 PCB
    [ESPTiny1614.kicad_pcb, ESPTiny1614.sch]
2021-07-14 Update README: Use any I2C device instead of ESP01
2021-07-14 Update silk screen
    [ESPTiny1614.kicad_pcb]
2021-07-14 Update 3V3 plane
    [ESPTiny1614.kicad_pcb]
2021-07-14 Add thermal isolation for front solder jumper
    [ESPTiny1614.kicad_pcb]
2021-07-15 Silkscreen update
    [ESPTiny1614.kicad_pcb]
2021-07-15 Add empty PCB images
2021-07-15 Silk screen update
    [ESPTiny.kicad_pcb]
2021-07-15 Update 1614 front silkscreen
    [ESPTiny1614.kicad_pcb]
2021-07-16 Change solder jumper footprint with thermal insulation
    [ESPTiny1614.kicad_pcb]
2021-07-16 revert pin comment
2021-07-18 Fix RST to A1
    [ESPTiny1614.kicad_pcb, ESPTiny1614.sch]
2021-07-18 Fix RST to B3
    [ESPTiny1614.kicad_pcb, ESPTiny1614.sch]
2021-07-19 Fix 4Mhz timing
    [ESPTiny1614.kicad_pcb]
2021-07-19 Update 16x2 PCB silk, 1.0 production
    [ESPTiny1614.kicad_pcb, ESPTiny1614.sch]
2021-07-26 Start on 402 SMD PCB
    [ESPTiny402.sch]
2021-07-29 Add ESPTinyx02
    [ESPTiny402.kicad_pcb]
2021-07-29 Update 4x2 and README
    [ESPTiny402.kicad_pcb, ESPTiny402.sch]
2021-07-29 C3 -> C2 rename
    [ESPTiny402.kicad_pcb, ESPTiny402.sch]
2021-07-29 Remove some support 3V3 tracks
    [ESPTiny402.kicad_pcb]
2021-07-29 Better power routing
    [ESPTiny402.kicad_pcb]
2021-07-29 Fix silk screen back
    [ESPTiny402.kicad_pcb]
2021-07-29 Fix silk screens
    [ESPTiny402.kicad_pcb]
2021-07-29 Improve routing
    [ESPTiny402.kicad_pcb]
2021-07-29 Update silk screen attiny84
    [ESPTiny.kicad_pcb]
2021-07-30 Minor layout changes
    [ESPTiny402.kicad_pcb]
2021-07-31 Led to 1206 size
    [ESPTiny402.kicad_pcb, ESPTiny402.sch]
2021-07-31 Minor routing updates
    [ESPTiny402.kicad_pcb]
2021-07-31 Larger silk text
    [ESPTiny402.kicad_pcb]
2021-07-31 Minor silk updates
    [ESPTiny402.kicad_pcb]
2021-08-01 SOT89 version
    [ESPTiny402-SOT89.kicad_pcb, ESPTiny402-SOT89.sch]
2021-08-01 SOT89 version reorder
    [ESPTiny402-SOT89.kicad_pcb]
2021-08-02 SOT89 add TH position
    [ESPTiny402-SOT89.kicad_pcb]
2021-08-02 Update 402 layout and images
    [ESPTiny402.kicad_pcb]
2021-08-02 Update 402 layout
    [ESPTiny402-SOT89.kicad_pcb, ESPTiny402.kicad_pcb]
2021-08-10 A1 voltage measurement
2021-08-10 production 402 SOT89
    [ESPTiny402-SOT89.kicad_pcb]
2021-08-23 Fix voltage calculation (use unsigned long)
    [ESPTiny1614.ino, ESPTiny44-A1.ino, ESPTiny44.ino]
2021-08-24 Version 2.0 Add crystal and move ESP reset to other pin
    [ESPTiny1614.kicad_pcb, ESPTiny1614.sch]
2021-08-24 Silk screen
    [ESPTiny1614.kicad_pcb]
2021-08-24 Update layout of MCP1700 and power pins
    [ESPTiny1614.kicad_pcb, ESPTiny1614.sch]
2021-09-05 Fix interrupt code
2021-09-19 Add capacitors to 32768 crystal
    [ESPTiny1614.kicad_pcb, ESPTiny1614.sch]
2021-09-20 Better silk 1614 and improve battery code
    [ESPTiny1614.kicad_pcb]
2021-09-20 Better silk 1614
    [ESPTiny1614.kicad_pcb]
2021-10-13 Adjust clock and guard against low battery
2025-03-12 Update for KiCad 9.0
    [ESPTiny.kicad_pcb, ESPTiny.kicad_sch, ESPTiny1614.kicad_pcb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]
2025-03-13 Minor cosmetic cleanups
    [ESPTiny.kicad_pcb, ESPTiny.kicad_sch, ESPTiny1614.kicad_pcb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]
2025-03-18 adjust millis() while sleeping
2025-03-19 support shorter RTC periods (eg 1000ms instead of 2000ms)
    [ESPTiny402.ino]
2025-03-19 Fix ticks interrupt handling
    [ESPTiny402.ino]
2025-03-25 Test sleep timer code
